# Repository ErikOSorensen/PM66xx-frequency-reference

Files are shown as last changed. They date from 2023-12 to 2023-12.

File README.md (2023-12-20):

# PM66xx-frequency-reference

The plan is to build a good 10MHz reference for a PM6674 frequency counter (and those that are related).
This will be a gift to a lucky owner of such a counter.

Inspiration (and physical measurements) are taken from [The sync channel](https://syncchannel.blogspot.com/2016/04/flukephilips-pm66xx-frequency-counter.html),
but I am not so sure about using the internal voltage reference of the oscillator module. I would rather use an external low tempco 
reference such as the [ADR434BRZ](https://www.analog.com/en/products/adr434.html), which means I also need to add
a voltage regulator for this chip.

Looking at the output of my spare CTS 970 oscillator, I think it would also be nice to provide 
a filter on the output, and I've added a 10.5 MHz low pass filter on the bottom of the board.

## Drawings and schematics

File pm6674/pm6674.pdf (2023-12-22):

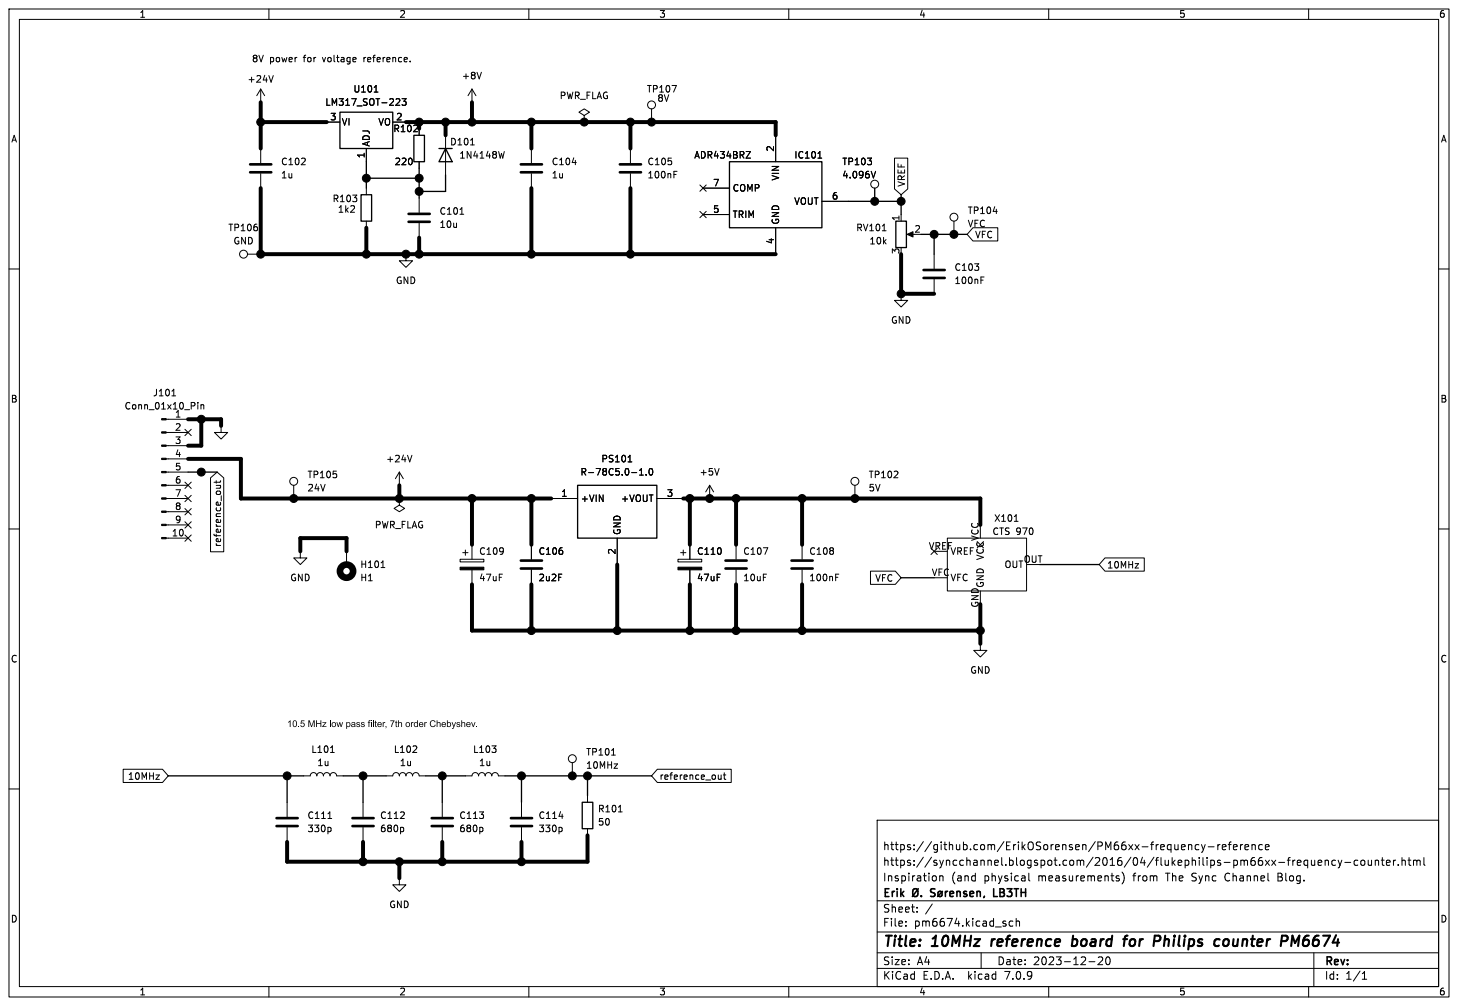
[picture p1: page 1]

8V power for voltage reference.

2 +VOUT 3 PS101 R-78C5.0-1.0 GND GND OUT VCC OUT VCC

10.5 MHz low pass filter, 7th order Chebyshev. (https://markimicrowave.com/technical-resources/tools/lc-filter-design-tool/)

https://github.com/ErikOSorensen/PM66xx-frequency-reference
https://syncchannel.blogspot.com/2016/04/flukephilips-pm66xx-frequency-counter.html

Id: 1/1 Title: 10MHz reference board for Philips counter PM6674

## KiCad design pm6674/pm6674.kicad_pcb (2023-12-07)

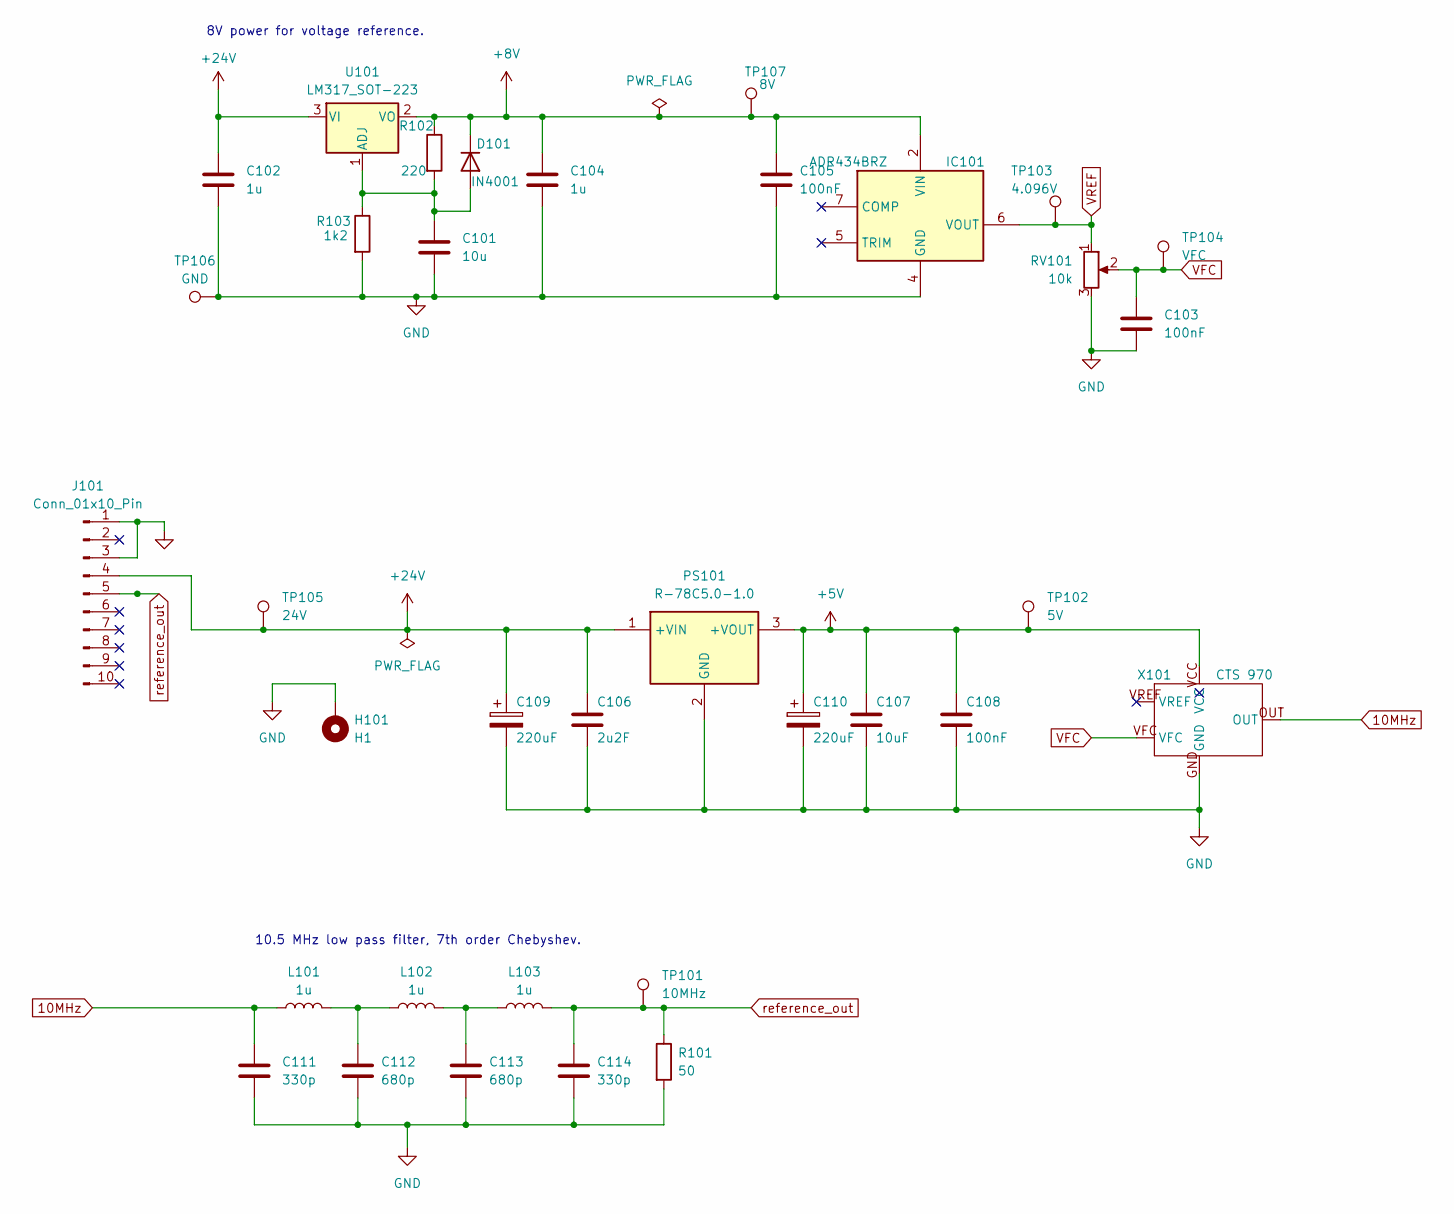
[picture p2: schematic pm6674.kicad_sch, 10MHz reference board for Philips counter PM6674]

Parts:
C101: 10u; C_0805_2012Metric
C102, C104: 1u; C_0805_2012Metric
C103, C105, C108: 100nF; C_0805_2012Metric
C106: 2u2F; C_0805_2012Metric
C107: 10uF; C_0805_2012Metric
C109, C110: 220uF; CP_Elec_8x10.5
C111, C114: 330p; C_0805_2012Metric
C112, C113: 680p; C_0805_2012Metric
D101: IN4001; D_SOD-123F
H101: H1; MountingHole_3.2mm_M3_DIN965_Pad_TopBottom
IC101: ADR434BRZ; SOIC127P600X175-8N; Mouser Part Number 584-ADR434BRZ
J101: Conn_01x10_Pin; Molex 22-14-2104
L101, L102, L103: 1u; L_0805_2012Metric
PS101: R-78C5.0-1.0; R78C1210; Mouser Part Number 919-R-78C5.0-1.0
R101: 50; R_0805_2012Metric
R102: 220; R_0805_2012Metric
R103: 1k2; R_0805_2012Metric
RV101: 10k; M64Y503KB40
TP101: 10MHz; PinHeader_1x01_P2.54mm_Vertical
TP102: 5V; PinHeader_1x01_P2.54mm_Vertical
TP103: 4.096V; PinHeader_1x01_P2.54mm_Vertical
TP104: VFC; PinHeader_1x01_P2.54mm_Vertical
TP105: 24V; PinHeader_1x01_P2.54mm_Vertical
TP106: GND; PinHeader_1x01_P2.54mm_Vertical
TP107: 8V; PinHeader_1x01_P2.54mm_Vertical
U101: LM317_SOT-223; SOT-223-3_TabPin2
X101: CTS 970; CTS1960017

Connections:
10MHz: C111.1, L101.1, X101.OUT
+5V: C107.1, C108.1, C110.1, PS101.3 (+VOUT), TP102.1, X101.VCC
+8V: C104.1, C105.1, D101.1 (K), IC101.2 (VIN), R102.1, TP107.1, U101.2 (VO)
+24V: C102.1, C106.1, C109.1, J101.4, PS101.1 (+VIN), TP105.1, U101.3 (VI)
GND: C101.2, C102.2, C103.2, C104.2, C105.2, C106.2, C107.2, C108.2, C109.2, C110.2, C111.2, C112.2, C113.2, C114.2, H101.1, IC101.4 (GND), J101.1, J101.3, PS101.2 (GND), R101.2, R103.2, RV101.3, TP106.1, X101.GND
unnamed: C112.1, L101.2, L102.1
unnamed: C113.1, L102.2, L103.1
unnamed: C101.1, D101.2 (A), R102.2, R103.1, U101.1 (ADJ)
VFC: C103.1, RV101.2, TP104.1, X101.VFC
VREF: IC101.6 (VOUT), RV101.1, TP103.1
reference_out: C114.1, J101.5, L103.2, R101.1, TP101.1

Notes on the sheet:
10.5 MHz low pass filter, 7th order Chebyshev.
8V power for voltage reference.

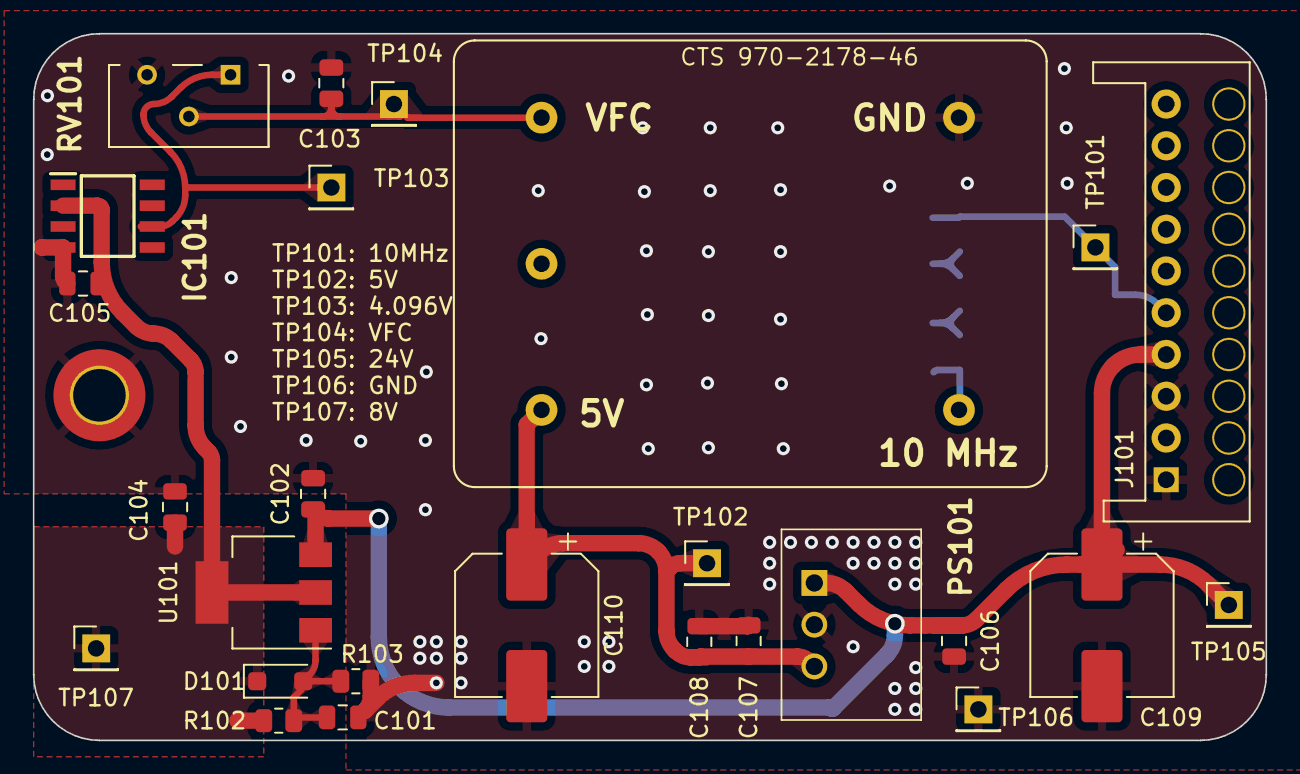
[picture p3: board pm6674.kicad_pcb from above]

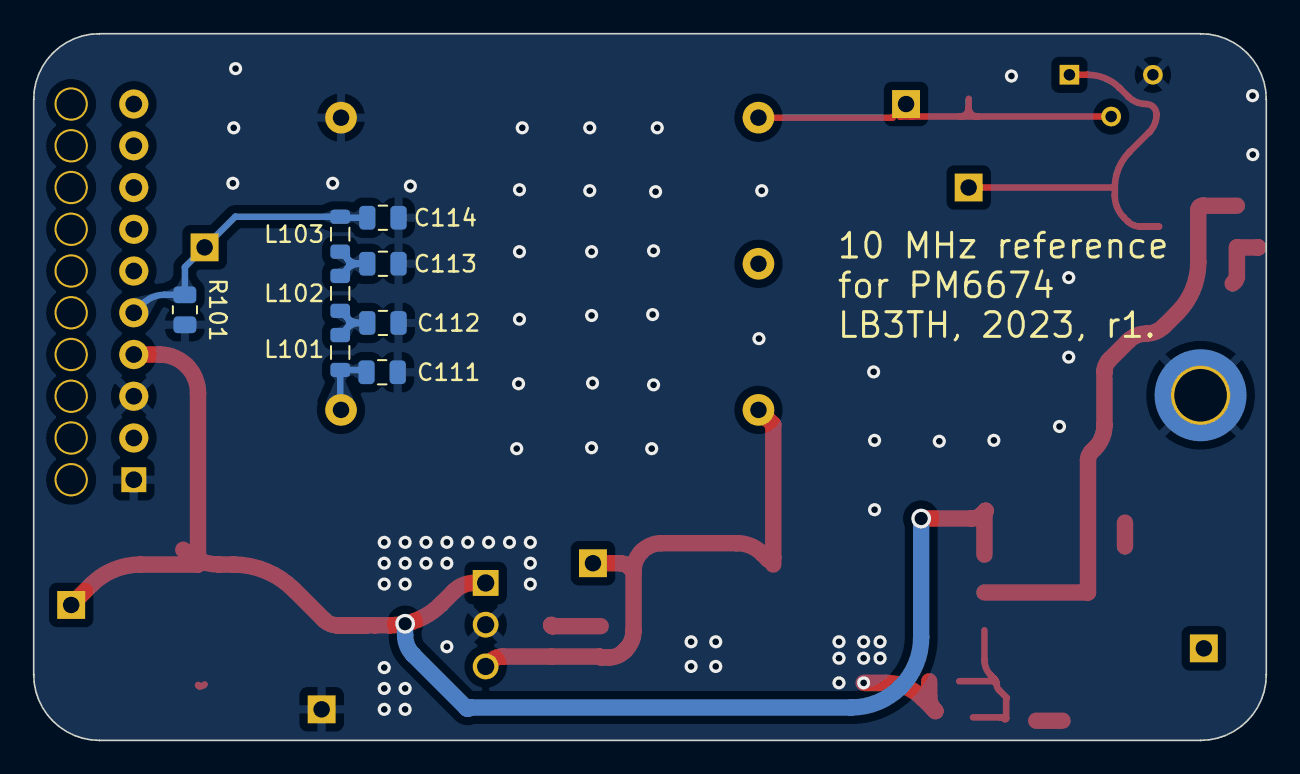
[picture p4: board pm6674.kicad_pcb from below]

Board: 2 copper layers, 75.0 x 43.0 mm, 35 parts (8 on the bottom side), 11 nets.

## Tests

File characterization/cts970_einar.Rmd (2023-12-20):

---
title: "Characterization of oscillator (CTS 970), first board built for Einar"
author: "Erik Ø. Sørensen"
date: "`r Sys.Date()`"
output: html_document
---

```{r setup, include=FALSE}
knitr::opts_chunk$set(echo = TRUE)
library(tidyverse)
```

# Current drawn

From an ambient temperature, I measured how much current the oscillator
drew from the power supply in the first minutes (at 5V). I measured
the current draw every 10th second.

```{r include=FALSE}
is <- c(0.620, 0.623, 0.623, 0.623, 0.623, 0.620, 
        0.622, 0.622, 0.621, 0.413, 0.364, 0.344,
        0.333, 0.323, 0.316, 0.310, 0.303, 0.298,
        0.293, 0.291, 0.285, 0.290, 0.292, 0.292,
        0.292, 0.290) * 1000
start <- as_datetime("2023-12-20T204800")
second <- as_datetime("2023-12-20T204810")                
ts <- seq(start, by=difftime(second,start),length.out=26)
df <- tibble(current=is, time=ts)
```

```{r echo=FALSE}
df |> ggplot(aes(x=time, y=current)) +
  geom_line() +
  theme_minimal() +
  labs(x = "Measurement moment", y = "Current draw [mA]",
       title="The oscillator warming up") +
  theme(plot.title.position = "plot")
```

Very slowly, the current draw continued to drop, at 22:20 the current drawn was 236 mA.

# Frequency vs control voltage

If the frequency generated cannot be controlled in a proper window around 10MHz,
the oscillator might be too old and for use. I measured the frequency
generated for some control voltages, and this doesn't seem like a problem.

```{r echo=FALSE}
df2 <- tibble(V_control = c(2.000, 2.100, 2.200, 2.300, 2.400),
              f_out = c(9999999.1, 9999999.490, 9999999.965, 10000000.246, 10000000.621))
df2 |> ggplot(aes(x=V_control, y=f_out)) +
  geom_line() +
  geom_point() + 
  theme_minimal() +
  scale_y_continuous(labels = scales::label_comma()) +
  labs(x="Control voltage [V]", y = "Frequency [Hz]", 
       title="Frequency vs control voltage") +
  theme(plot.title.position = "plot")
dlta <- (max(df2$f_out) - min(df2$f_out))/(max(df2$V_control)-min(df2$V_control))
```

The frequency was measured by my Agilent 53131A with a GPSDO reference
(with a 1s gate time). This seems fairly linear, with about
`r format(dlta, digits=2)`
Hz/V. The potentiometer on the board has 4.096V from the voltage reference 
over 23 turns, so this will give about `r format(dlta * 4.096 /23, digits=2)` 
Hz/turn which should make it possible to  calibrate it fairly precisely.

# Amplitude

Running freely, without a load, I measured 2.3V peak-to-peak. With the filtration
and the 50 Ohm on-board load resistor that I have adopted from previous designs I measure
around 1V peak-to-peak, which is more or less in line with a 50 Ohm internal
impedance of the oscillator, and a small insertion loss of the low pass filter
I added.

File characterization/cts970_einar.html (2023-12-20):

# Characterization of oscillator (CTS 970), first board built for Einar

#### Erik Ø. Sørensen

#### 2023-12-21

# Current drawn

From an ambient temperature, I measured how much current the oscillator drew from the power supply in the first minutes (at 5V). I measured the current draw every 10th second.

Very slowly, the current draw continued to drop, at 22:20 the current drawn was 236 mA.

# Frequency vs control voltage

If the frequency generated cannot be controlled in a proper window around 10MHz, the oscillator might be too old and for use. I measured the frequency generated for some control voltages, and this doesn’t seem like a problem.

The frequency was measured by my Agilent 53131A with a GPSDO reference (with a 1s gate time). This seems fairly linear, with about 3.8 Hz/V. The potentiometer on the board has 4.096V from the voltage reference over 23 turns, so this will give about 0.68 Hz/turn which should make it possible to calibrate it fairly precisely.

# Amplitude

Running freely, without a load, I measured 2.3V peak-to-peak. With the filtration and the 50 Ohm on-board load resistor that I have adopted from previous designs I measure around 1V peak-to-peak, which is more or less in line with a 50 Ohm internal impedance of the oscillator, and a small insertion loss of the low pass filter I added.

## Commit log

2023-12-07 First cut at board (sent to JLCPCB),
    [pm6674.kicad_pcb, pm6674.kicad_sch]
2023-12-20 Final schematics of built-up and tested board.
    [pm6674.kicad_sch]
2023-12-20 Built board and measured the oscillator.
2023-12-22 Added github reference in schematic.
    [pm6674.kicad_sch]
